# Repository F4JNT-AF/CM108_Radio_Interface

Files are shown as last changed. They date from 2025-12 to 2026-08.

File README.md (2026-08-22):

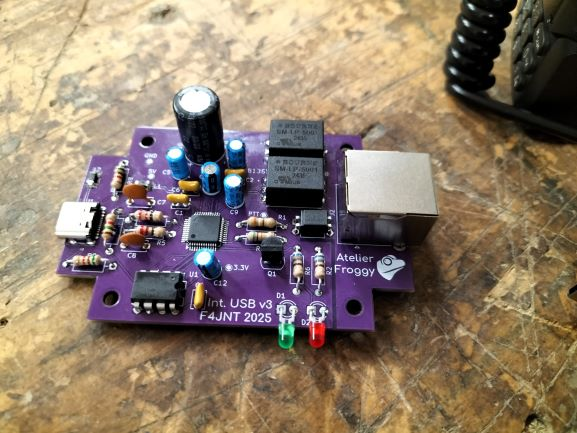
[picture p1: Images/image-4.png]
Interface


# [FR] (EN below)
## Description
Une interface basique USB entre une radio et un PC. Rien de révolutionnaire, j'ai essayé de mettre le maximum de composants traversants, avec deux exceptions assez techniques, le CM108 lui-même (pas trop le choix quand on veut faire une interface a base de CM108 :) ) et le connecteur USB-C (très pratique pour connecter en direct au téléphone sans OTG).

Avec cette interface, il est possible de faire de nombreux modes: packet, SSTV, RTTY, Rattlegram (COFDMTV), FT8 ... la seule limite étant ce que votre PC peut faire et la bande passante du transfo audio (il devrait être possible de ponter le transfo pour faire du packet en 9600 bauds sur les radios qui peuvent).

Une EEPROM (93C46B) peut être montée et servir a stocker un nom personnalisé pour l'interface ainsi que des paramètres audio par défaut.

[Objet d'un atelier en Mars 2025 a l'ARA35](https://ara35.fr/ce-soir-la-on-a-fabrique-des-interfaces-modes-numeriques-au-radio-club-f4kio/)

## Pinout connecteur RJ45
Le connecteur vers la radio est un RJ45. Le pinout est:
1. Speaker radio
2. Micro radio
3. PTT
4. GND radio
5. GND radio
6. GND radio
7. GND radio
8. GND radio

## Configuration de l'EEPROM
Utiliser le fichier .cfg (optionnel: mettre un numéro de série) ou .hex avec [mon configurateur d'EEPROM pour CM108B](https://github.com/F4JNT-AF/CM108B_EEPROM_Manager).

## Note
Comme toutes les interfaces de ce type, elle est plutôt sensible aux retours RF, je conseille de mettre des ferrites, au moins sur le câble USB.

73, Axel F4JNT

# [EN]
## Description
A basic USB interface between a radio and a PC. Nothing groundbreaking, I tried to use the maximum number of through-hole components, with two exceptions that are tricky to solder, the CM108 itself (not much choice when your interface is CM108-based :) ) and the USB-C connector (very handy to connect).

With this interface, you can do a lot of modes such as packet, SSTV, RTTY, Rattlegram (COFDMTV), FT8 ... your only limits will be what your PC or phone can handle and the bandwidth of the audio transformer (it should be possible to do 9600 bauds packet on compatible radios by shunting the transformers)

An EEPROM (93C46B) can be populated and may store a custom device name and audio parameters.

[Did a kit + workshop at ARA35](https://ara35.fr/ce-soir-la-on-a-fabrique-des-interfaces-modes-numeriques-au-radio-club-f4kio/)

## RJ45 Pinout
Connector to radio is RJ45. Pinout:
1. Speaker radio
2. Mic radio
3. PTT
4. GND radio
5. GND radio
6. GND radio
7. GND radio
8. GND radio

## EEPROM configuration
Use the .cfg file (optional: put a serial number) or .hex file with [my CM108B EEPROM configurator](https://github.com/F4JNT-AF/CM108B_EEPROM_Manager).

## Note
Note: As all interfaces of this type, it is vulnerable to RF feedback, I'd advise to at least add some ferrites to USB cable.

73, Axel F4JNT

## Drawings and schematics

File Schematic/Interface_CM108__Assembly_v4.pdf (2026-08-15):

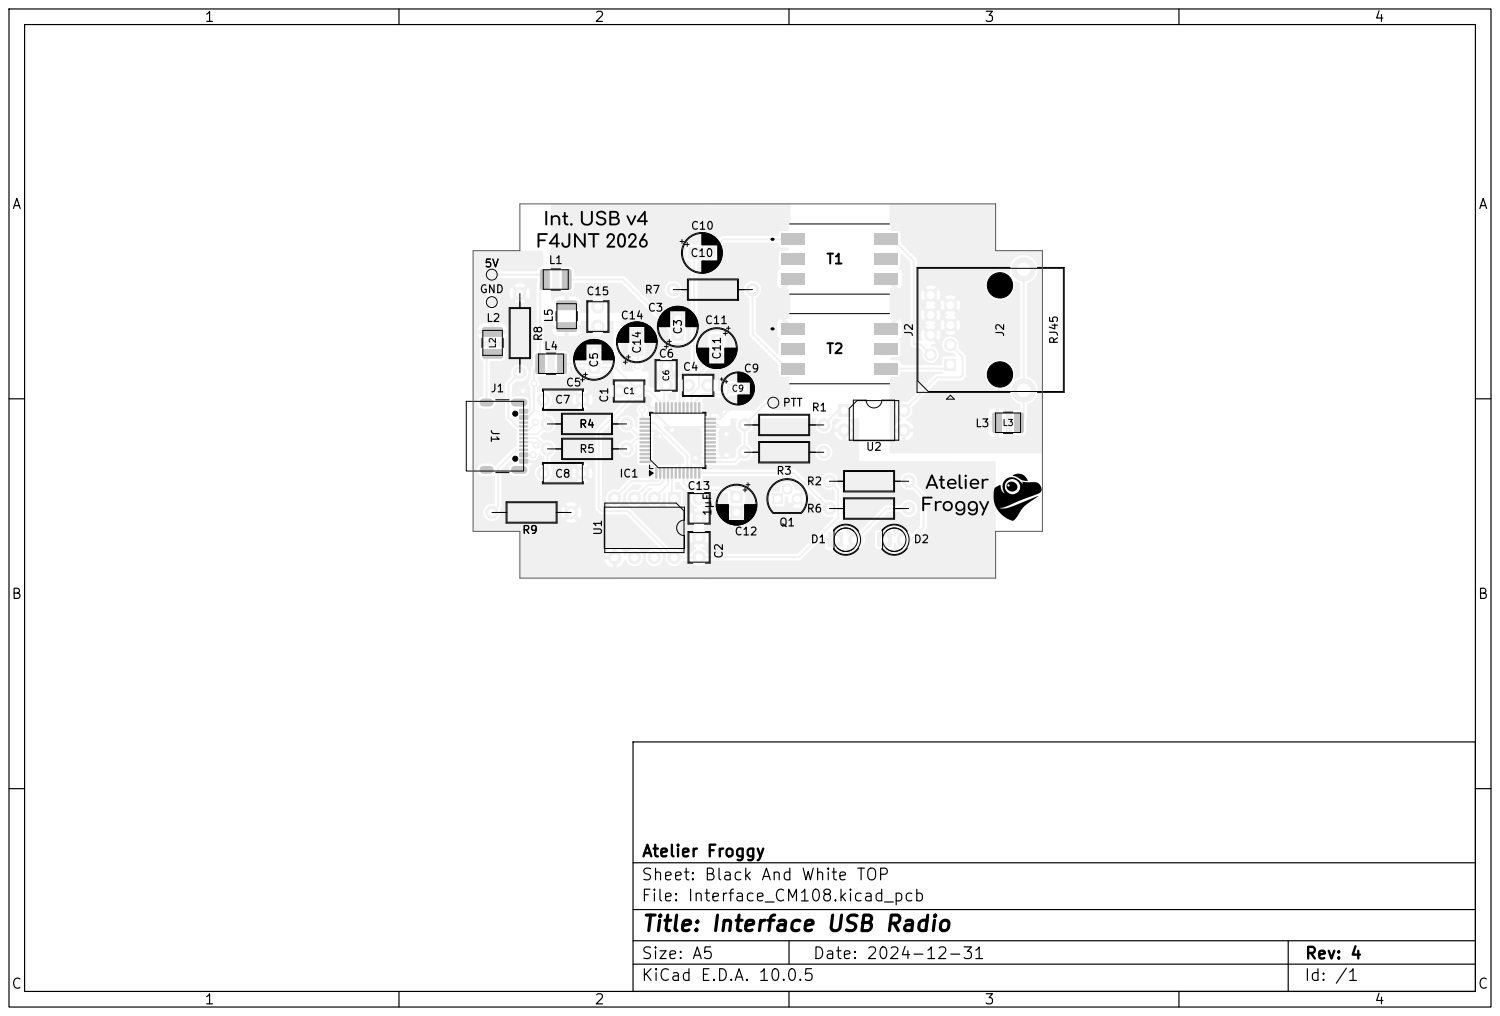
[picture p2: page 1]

Sheet: Black And White TOP
File: Interface_CM108.kicad_pcb
Title: Interface USB Radio
KiCad E.D.A. 10.0.5

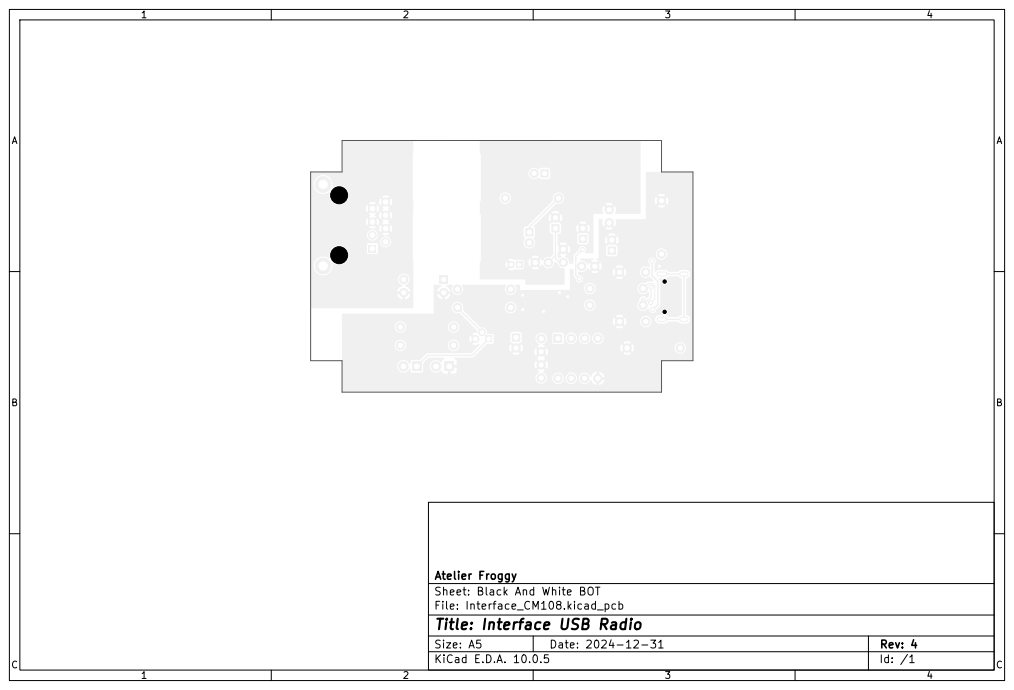
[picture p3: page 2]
C Date: 2024-12-31; Size: A5; Rev: 4

Atelier Froggy
Sheet: Black And White BOT
File: Interface_CM108.kicad_pcb
Title: Interface USB Radio
KiCad E.D.A. 10.0.5

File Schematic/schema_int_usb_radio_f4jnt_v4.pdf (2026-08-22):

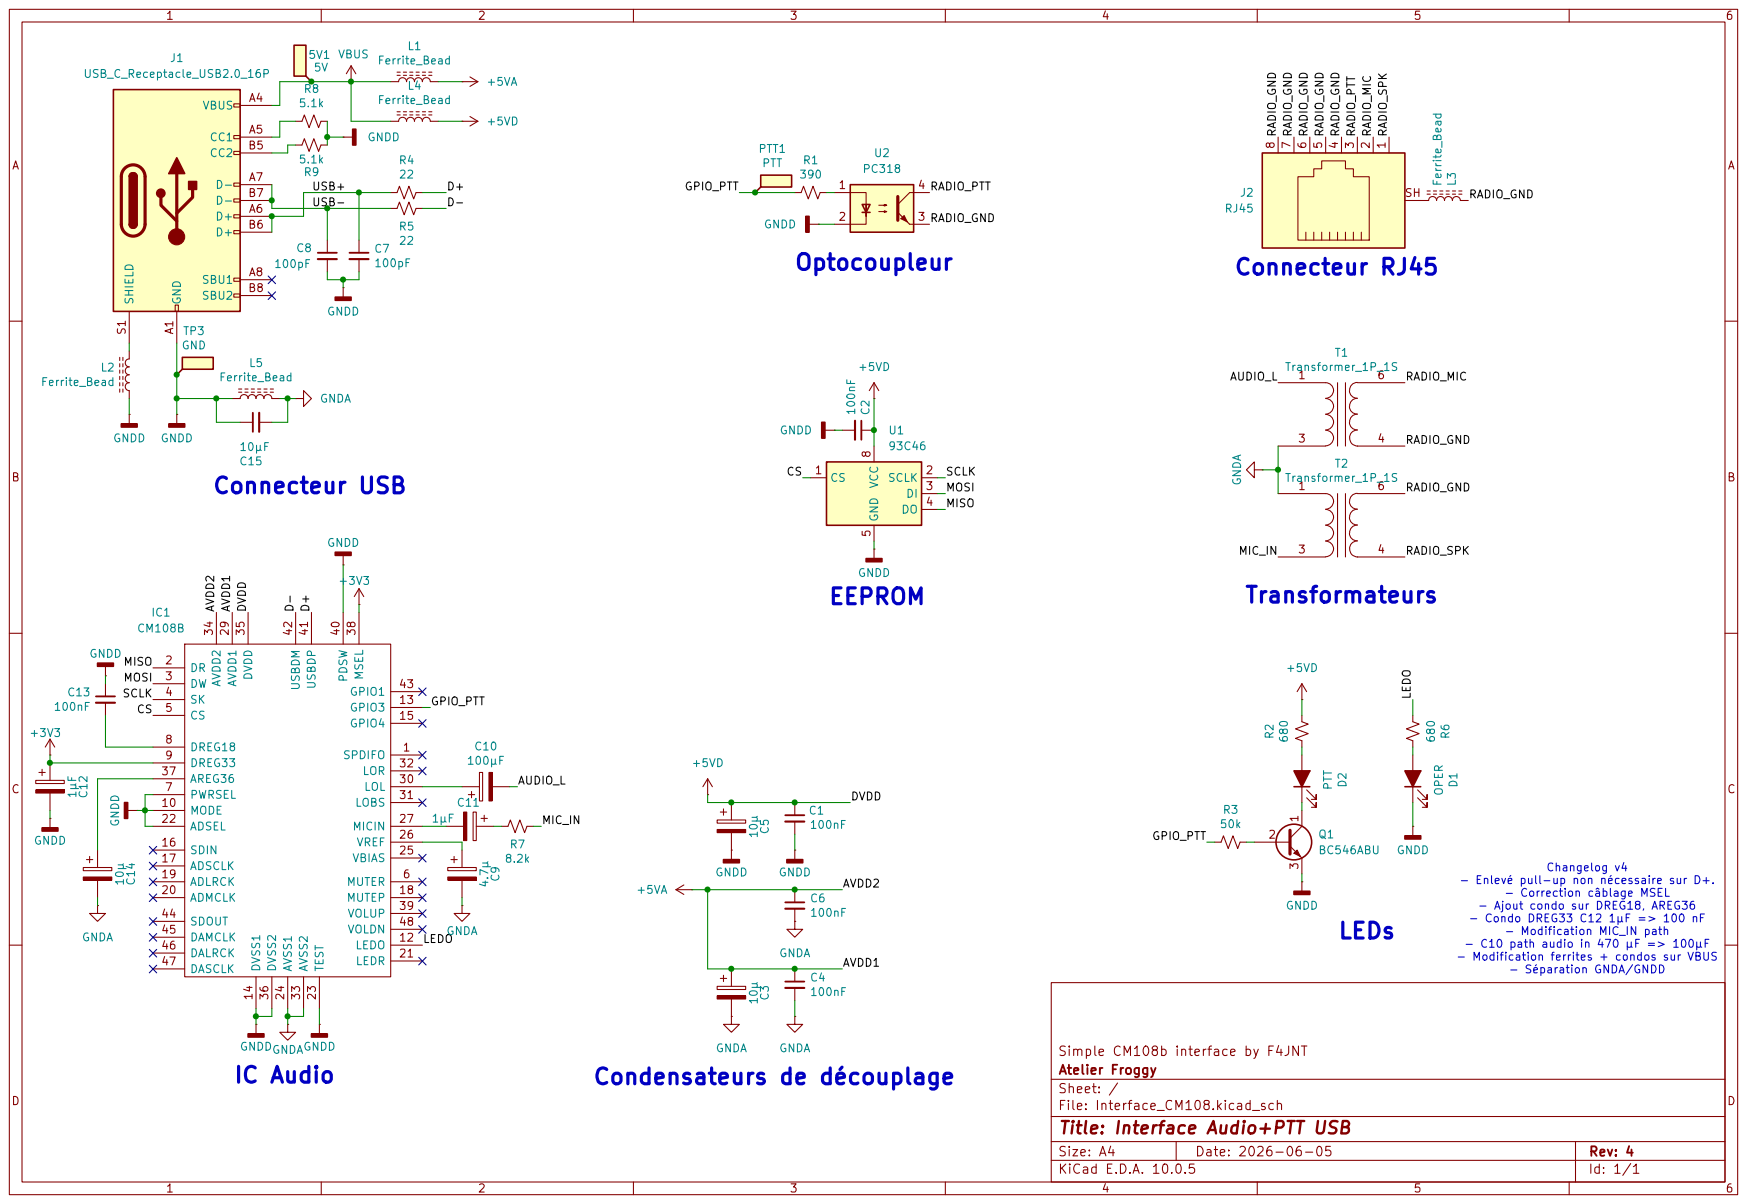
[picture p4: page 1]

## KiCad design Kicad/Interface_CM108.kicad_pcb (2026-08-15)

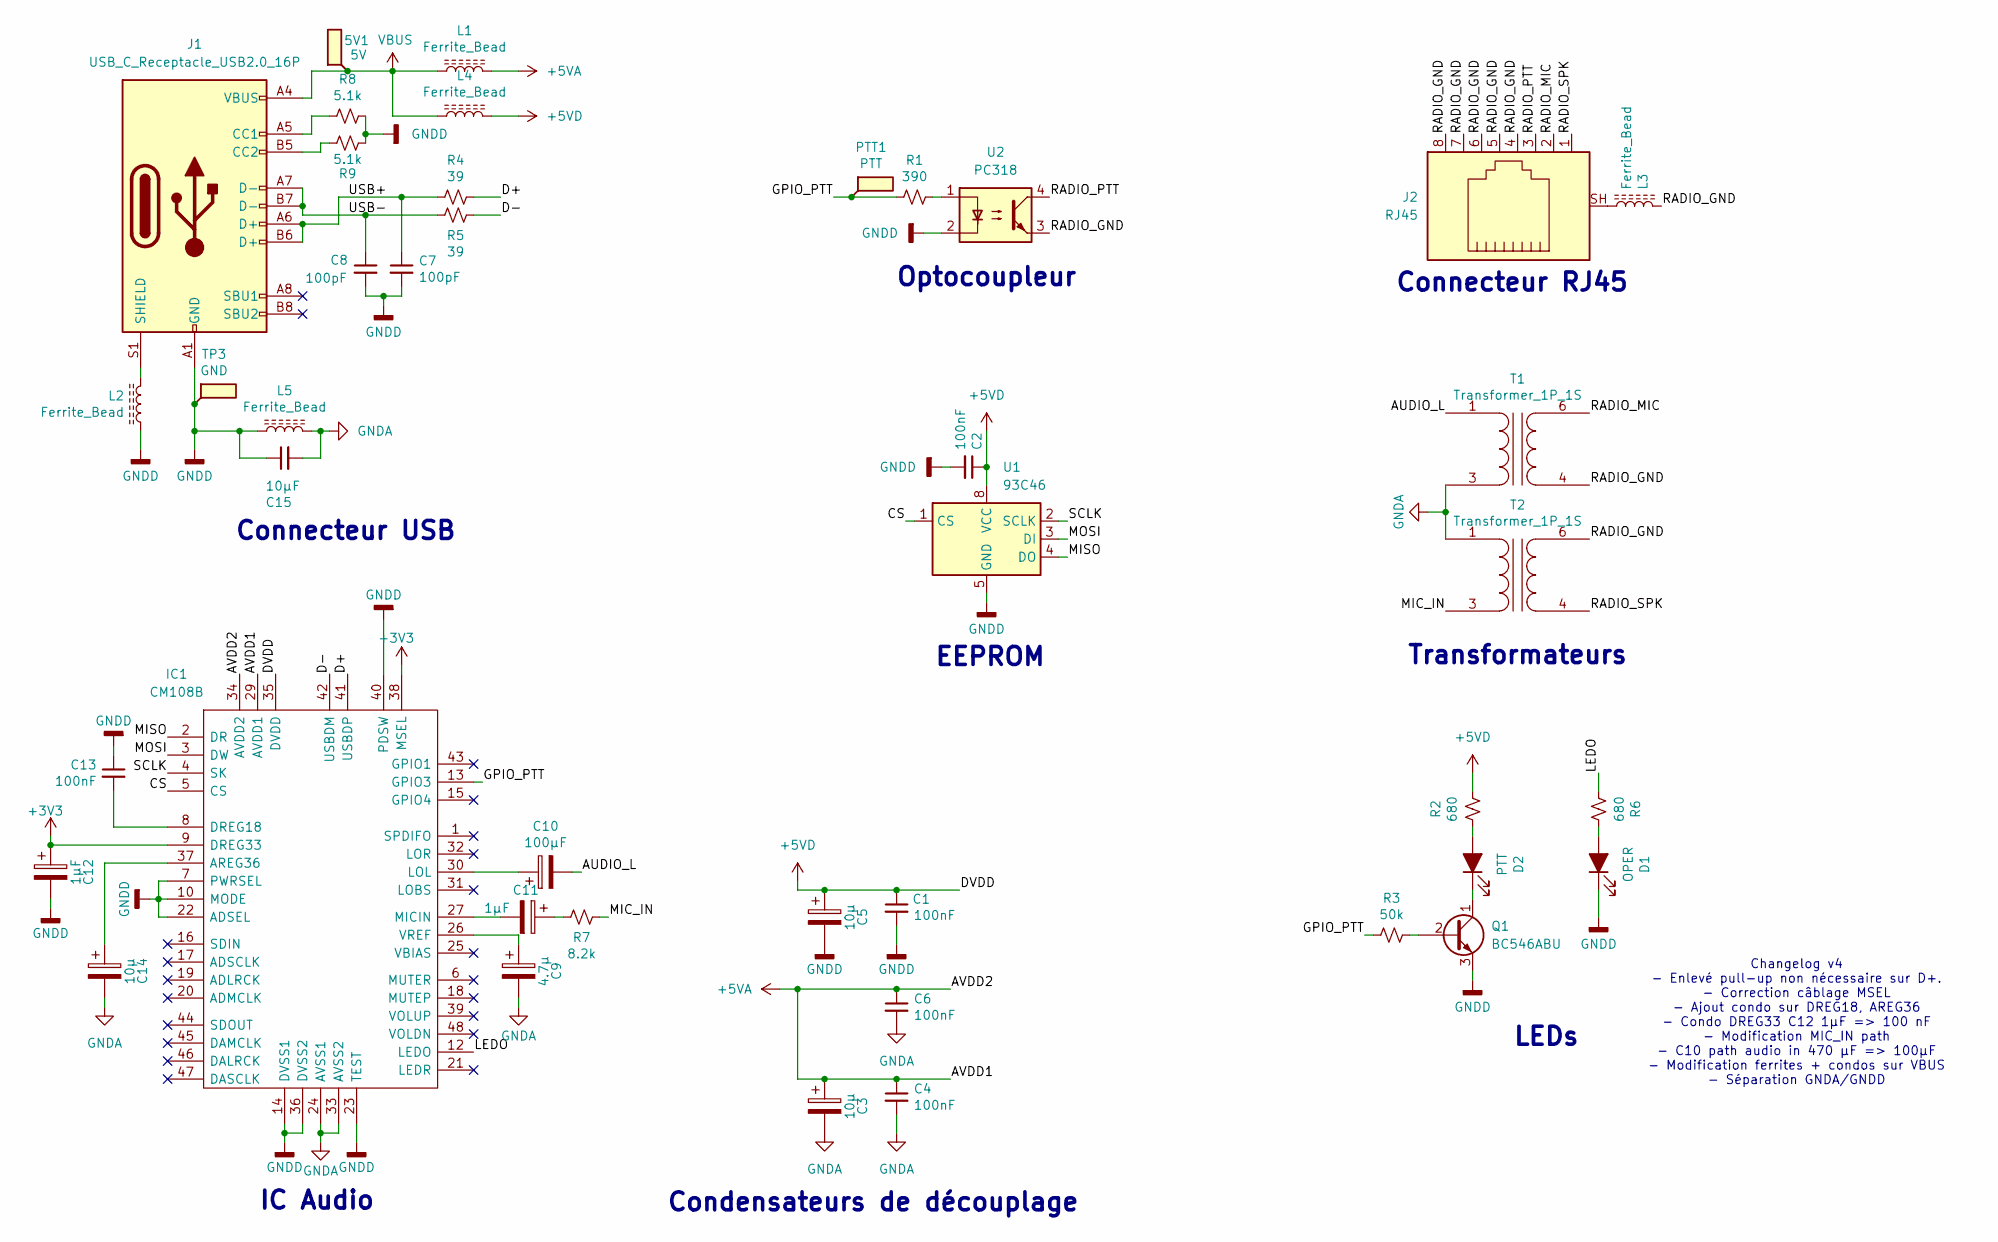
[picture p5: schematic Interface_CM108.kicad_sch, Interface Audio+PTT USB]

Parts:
5V1: 5V; TestPoint_Pad_D1.0mm
C1, C2, C4, C6, C13: 100nF; C_Disc_D3.8mm_W2.6mm_P2.50mm
C3, C5, C14: 10µ; CP_Radial_D5.0mm_P2.00mm
C7, C8: 100pF; C_Disc_D5.0mm_W2.5mm_P5.00mm
C9: 4.7µ; CP_Radial_D4.0mm_P1.50mm
C10: 100μF; CP_Radial_D5.0mm_P2.00mm
C11, C12: 1µF; CP_Radial_D5.0mm_P2.00mm
C15: 10µF; C_Disc_D3.8mm_W2.6mm_P2.50mm
D1: OPER; LED_D3.0mm
D2: PTT; LED_D3.0mm
IC1: CM108B; LQFP-48_7x7mm_P0.5mm
J1: USB_C_Receptacle_USB2.0_16P; USB_C_Receptacle_GCT_USB4105-xx-A_16P_TopMnt_Horizontal
J2: RJ45; RJ45_Ninigi_GE
L1, L2, L3, L4, L5: Ferrite_Bead; L_1210_3225Metric
PTT1: PTT; TestPoint_Pad_D1.0mm
Q1: BC546ABU; TO-92
R1: 390; R_Axial_DIN0207_L6.3mm_D2.5mm_P10.16mm_Horizontal
R2, R6: 680; R_Axial_DIN0207_L6.3mm_D2.5mm_P10.16mm_Horizontal
R3: 50k; R_Axial_DIN0207_L6.3mm_D2.5mm_P10.16mm_Horizontal
R4, R5: 39; R_Axial_DIN0207_L6.3mm_D2.5mm_P10.16mm_Horizontal
R7: 8.2k; R_Axial_DIN0207_L6.3mm_D2.5mm_P10.16mm_Horizontal
R8, R9: 5.1k; R_Axial_DIN0207_L6.3mm_D2.5mm_P10.16mm_Horizontal
T1, T2: Transformer_1P_1S; SMLP5001
TP3: GND; TestPoint_Pad_D1.0mm
U1: 93C46; DIP-8_W7.62mm
U2: PC318; DIP-4_W7.62mm

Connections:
+3V3: C12.1, IC1.9 (DREG33), IC1.38 (MSEL)
+5VA: C3.1, C4.1, C6.1, IC1.29 (AVDD1), IC1.34 (AVDD2), L1.2
+5VD: C1.1, C2.1, C5.1, IC1.35 (DVDD), L4.2, R2.1, U1.8 (VCC)
/AUDIO_L: C10.2, T1.1 (AA)
/CS: IC1.5 (CS), U1.1 (CS)
/D+: IC1.41 (USBDP), R4.1
/D-: IC1.42 (USBDM), R5.1
/GPIO_PTT: IC1.13 (GPIO3), PTT1.1, R1.2, R3.2; also elsewhere on the board
/LEDO: IC1.12 (LEDO), R6.2
/MIC_IN: R7.1, T2.3 (AB)
/MISO: IC1.2 (DR), U1.4 (DO)
/MOSI: IC1.3 (DW), U1.3 (DI)
/RADIO_GND: J2.4, J2.5, J2.6, J2.7, J2.8, L3.2, T1.4 (SA), T2.6 (SB), U2.3
/RADIO_MIC: J2.2, T1.6 (SB)
/RADIO_PTT: J2.3, U2.4
/RADIO_SPK: J2.1, T2.4 (SA)
/SCLK: IC1.4 (SK), U1.2 (SCLK)
/USB+: C7.1, J1.A6 (D+), J1.B6 (D+), R4.2
/USB-: C8.1, J1.A7 (D-), J1.B7 (D-), R5.2
GNDA: C3.2, C4.2, C6.2, C9.2, C14.2, C15.2, IC1.24 (AVSS1), IC1.33 (AVSS2), L5.2, T1.3 (AB), T2.1 (AA)
GNDD: C1.2, C2.2, C5.2, C7.2, C8.2, C12.2, C13.1, C15.1, D1.1 (K), IC1.7 (PWRSEL), IC1.10 (MODE), IC1.14 (DVSS1), IC1.22 (ADSEL), IC1.23 (TEST), IC1.36 (DVSS2), IC1.40 (PDSW), J1.A1 (GND), J1.A12 (GND), J1.B1 (GND), J1.B12 (GND), L2.1, L5.1, Q1.3 (E), R8.1, R9.1, TP3.1, U1.5 (GND), U2.2; also elsewhere on the board
unnamed: C11.1, R7.2
unnamed: D1.2 (A), R6.1
unnamed: D2.2 (A), R2.2
unnamed: D2.1 (K), Q1.1 (C)
unnamed: C14.1, IC1.37 (AREG36)
unnamed: C13.2, IC1.8 (DREG18)
unnamed: C10.1, IC1.30 (LOL)
unnamed: C11.2, IC1.27 (MICIN)
unnamed: C9.1, IC1.26 (VREF)
unnamed: J1.A5 (CC1), R8.2
unnamed: J1.B5 (CC2), R9.2
unnamed: J1.S1 (SHIELD), L2.2
unnamed: J2.SH, L3.1
unnamed: Q1.2 (B), R3.1
unnamed: R1.1, U2.1
VBUS: 5V1.1, J1.A4 (VBUS), J1.A9 (VBUS), J1.B4 (VBUS), J1.B9 (VBUS), L1.1, L4.1; also elsewhere on the board

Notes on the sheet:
EEPROM
Transformateurs
Connecteur USB
LEDs
Connecteur RJ45
Changelog v4 - Enlevé pull-up non nécessaire sur D+. - Correction câblage MSEL - Ajout condo sur DREG18, AREG36 - Condo DREG33 C12 1µF => 100 nF - Modification MIC_IN path - C10 path audio in 470 µF => 100µF - Modification ferrites + condos sur VBUS - Séparation GNDA/GNDD
Condensateurs de découplage
IC Audio
Optocoupleur

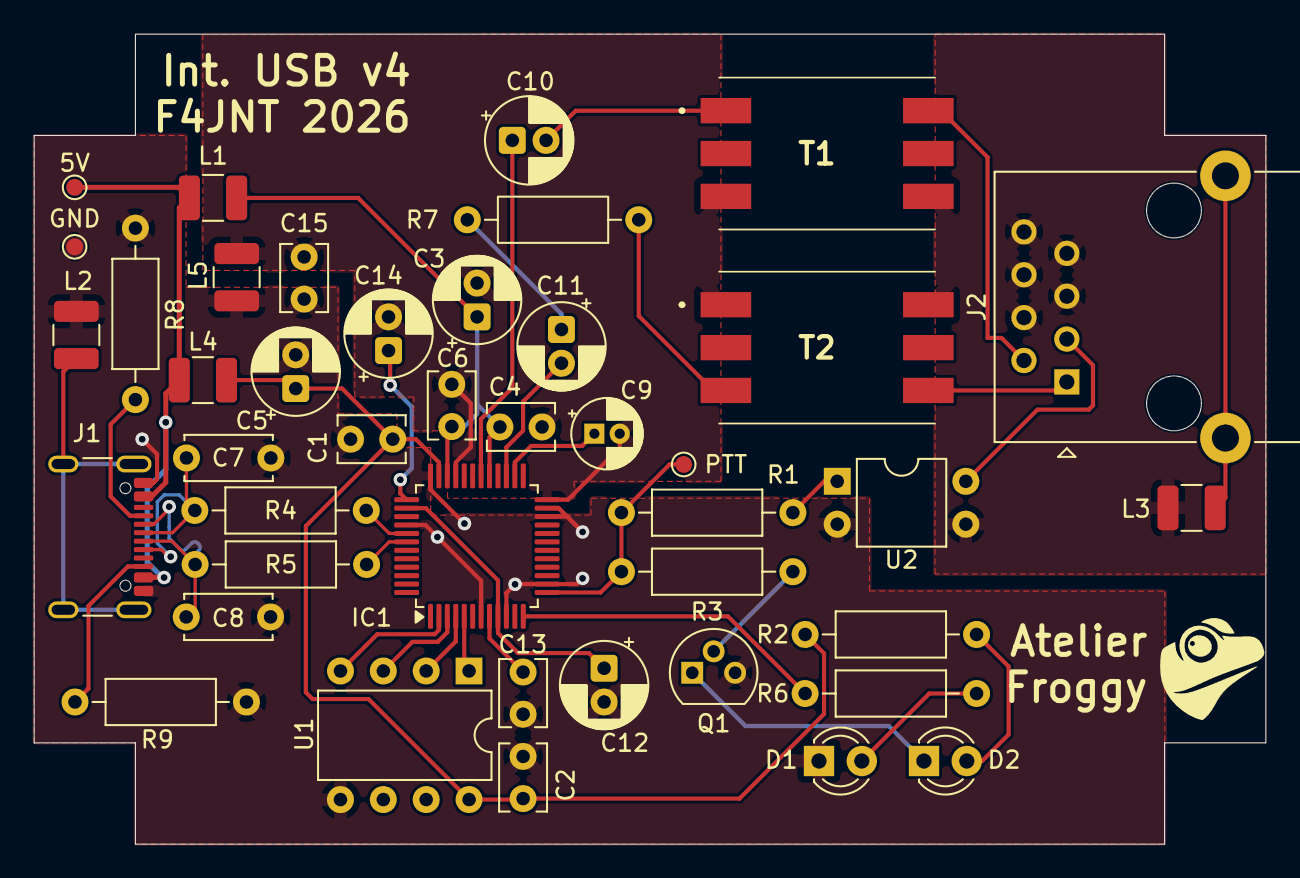
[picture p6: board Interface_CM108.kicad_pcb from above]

Board: 2 copper layers, 73.0 x 48.0 mm, 42 parts (0 on the bottom side), 37 nets.

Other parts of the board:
5V: 5V; TestPoint_Pad_D1.0mm
GND: GND; TestPoint_Pad_D1.0mm
PTT: PTT; TestPoint_Pad_D1.0mm

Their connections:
/GPIO_PTT: PTT.1 (1_1); also elsewhere on the board
GNDD: GND.1 (1_1); also elsewhere on the board
VBUS: 5V.1 (1_1); also elsewhere on the board

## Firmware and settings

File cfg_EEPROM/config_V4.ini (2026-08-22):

#hic sunt dracones :)

[Device]

#set to 1 if values in Audio_Config are to be used
audio_config_values_valid = 1

#set to 1 if custom product, manufacturer and serial strings are to be used
serial_number_enable_control = 1

#beware, issuing wrong VID & PID may remove support for CM108B specific functions on some software relying on this information. It will be 
VID = 0x0d8c
PID = 0x0012
serial_number = 1234ABCD

#30 char max, only Latin-1 ?
product_string = Interface F4JNT
manufacturer_string = Atelier Froggy

#All volumes are in dB, conversion to hex is done in script
[Audio_Config]

#DAC: initial default volume -10, min -37 (inconsistencies in datasheet), max 0
DAC_initial_volume = -10
#1: Use values in EEPROM, 0: Use default
DAC_min_max_volume_valid = 1
DAC_min_volume = -37
DAC_max_volume = 0

#ADC: initial default volume 8, min -22 (inconsistencies in datasheet), max 23
ADC_initial_volume = 8
#1: Use values in EEPROM, 0: Use default
ADC_min_max_volume_valid = 1
ADC_min_volume = -22 
ADC_max_volume = 23 

#AA: initial default volume -7, min -23, max 8
AA_initial_volume = -7
#1: Use values in EEPROM, 0: Use default
AA_min_max_volume_valid = 1
AA_min_volume = -23
AA_max_volume = 8

#0: 22dB, 1: 12dB (default) 
boost_mode = 1 

DAC_shutdown = 0

#Undocumented function. 1:enabled, 0:disabled(default)
total_power_control = 0

#1:enabled (default), 0:disabled
MIC_high_pass_filter = 1

#Undocumented function. May have something to do with ADC synchronization. 1:enabled, 0:disabled(default)
MIC_PLL_adjust = 0

#Undocumented function. #1:enabled (default), 0:disabled
MIC_boost = 0

# 1: headset, 0: speaker
DAC_output_terminal = 0

#Beware, disabling the HID will disable EEPROM management and GPIO control !
hid_enable = 1

# USB remote wakeup. 1:enabled, 0:disabled(default)
remote_wakeup = 0

# Undocumented function.
EE_OPTION2 = 0

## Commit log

2025-12-10 Initial Commit
    V3 as assembled in March
    [Interface_CM108.kicad_pcb, Interface_CM108.kicad_sch]
2026-08-15 Revision v4
    [Interface_CM108.kicad_pcb, Interface_CM108.kicad_sch]
2026-08-22 Corrected wrong USB resistor value
    [Interface_CM108.kicad_sch]
